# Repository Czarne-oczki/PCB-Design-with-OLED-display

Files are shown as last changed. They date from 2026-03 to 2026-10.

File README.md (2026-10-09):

# PCB Design with OLED display
# Overview
I am designing a 2-layer PCB that controls an OLED display via I2C, an SD card via SPI, and using a USB interface.

Zrzut ekranu 2026-10-08 175055

Zrzut ekranu 2026-10-08 175126

Zrzut ekranu 2026-10-08 174921

fourth board-1

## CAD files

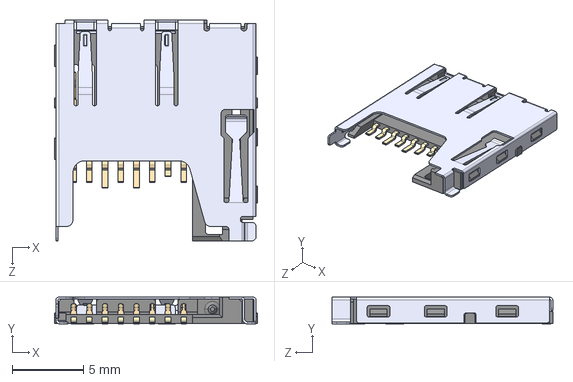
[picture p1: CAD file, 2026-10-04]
microsd/MEM2061-01-188-00-A_REVA.step
14.2 x 1.88 x 15.4 mm

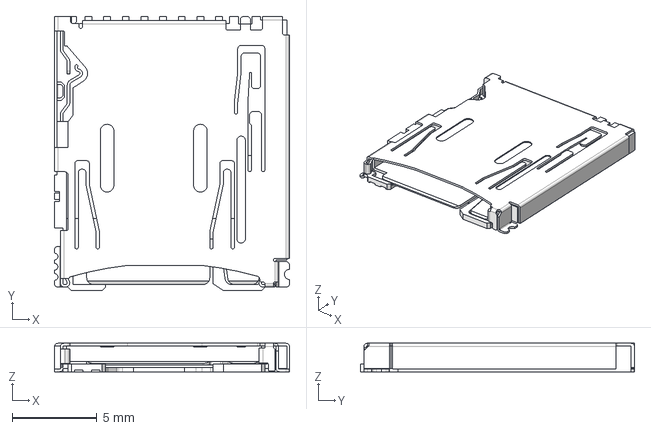
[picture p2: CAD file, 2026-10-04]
microsd3/DM3AT-SF-PEJM5.step
13.8 x 16.2 x 1.68 mm

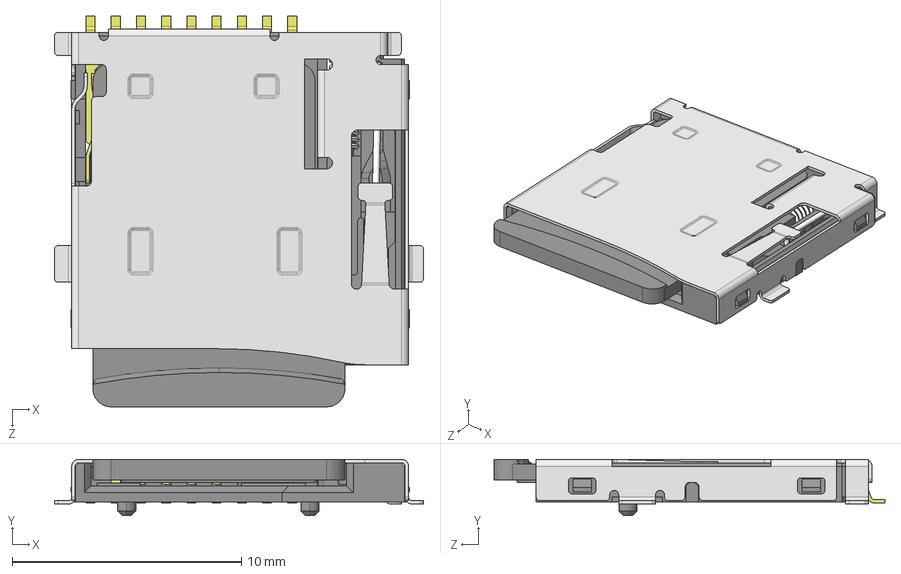
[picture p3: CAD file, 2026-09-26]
MicroSD_Socket.STEP
16.1 x 2.45 x 17.0 mm
Case^MicroSD_Socket
Insert^MicroSD_Socket
Brace^MicroSD_Socket
Spring^MicroSD_Socket
Lid^MicroSD_Socket
Pin_Middle^MicroSD_Socket x 5
Pin_Short^MicroSD_Socket
Pin_Long^MicroSD_Socket x 2
MicroSD_Card^MicroSD_Socket
Pin_CardIn^MicroSD_Socket

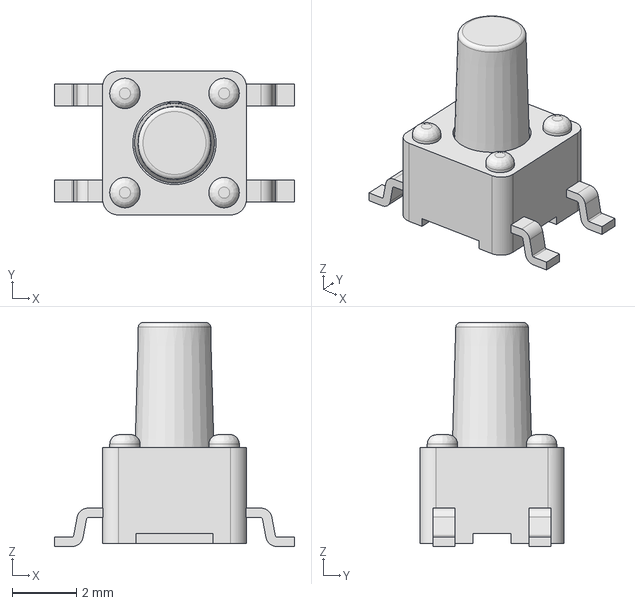
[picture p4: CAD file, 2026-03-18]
TL3305CF160QG.stp
7.50 x 4.50 x 7.00 mm

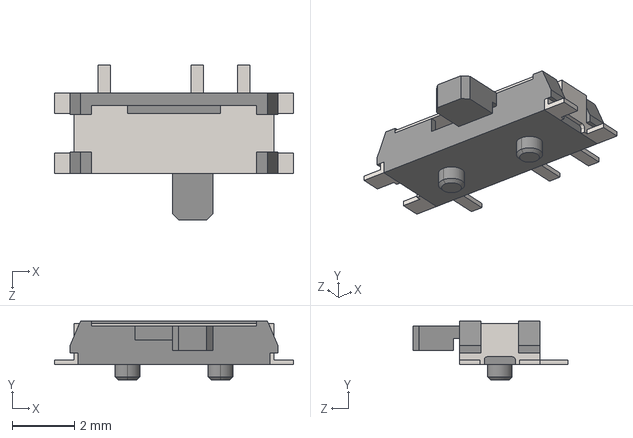
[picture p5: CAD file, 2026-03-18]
PCM12SMTR.stp
7.70 x 1.90 x 5.00 mm

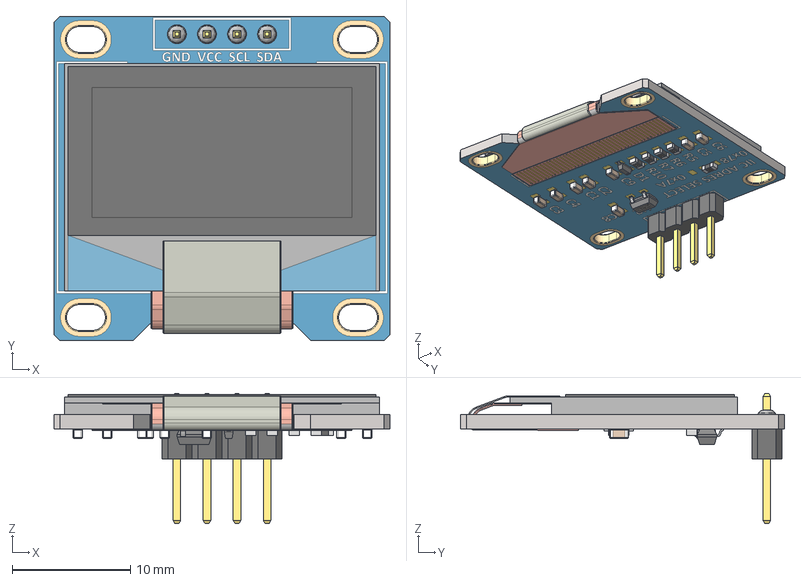
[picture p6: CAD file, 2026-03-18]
Pantalla OLED 0.96'' 128x64.stp
28.4 x 27.4 x 11.0 mm
SOT-23_TOR
RES_CR16_MTK_1 x 4
RES_CR16_MTK
SOD323F_DIO

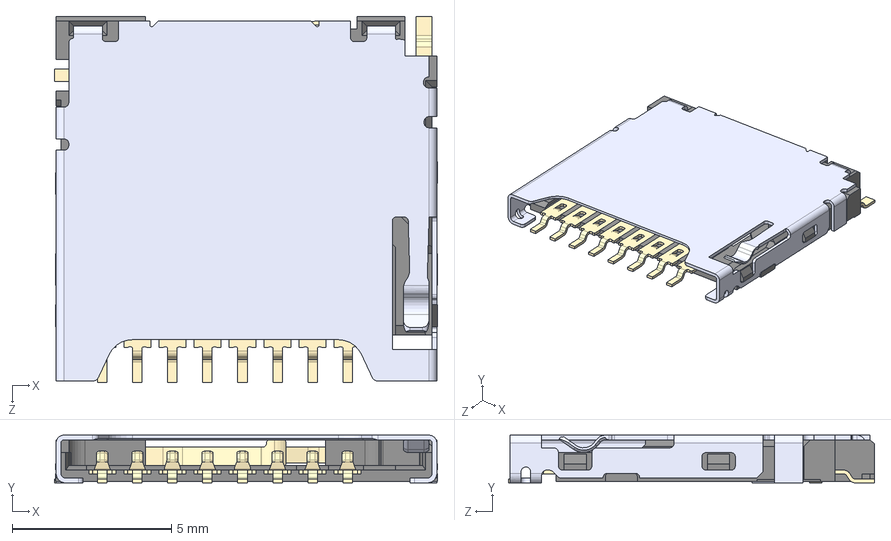
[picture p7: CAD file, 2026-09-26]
microsd2/1140084168.step
12.0 x 1.50 x 11.5 mm

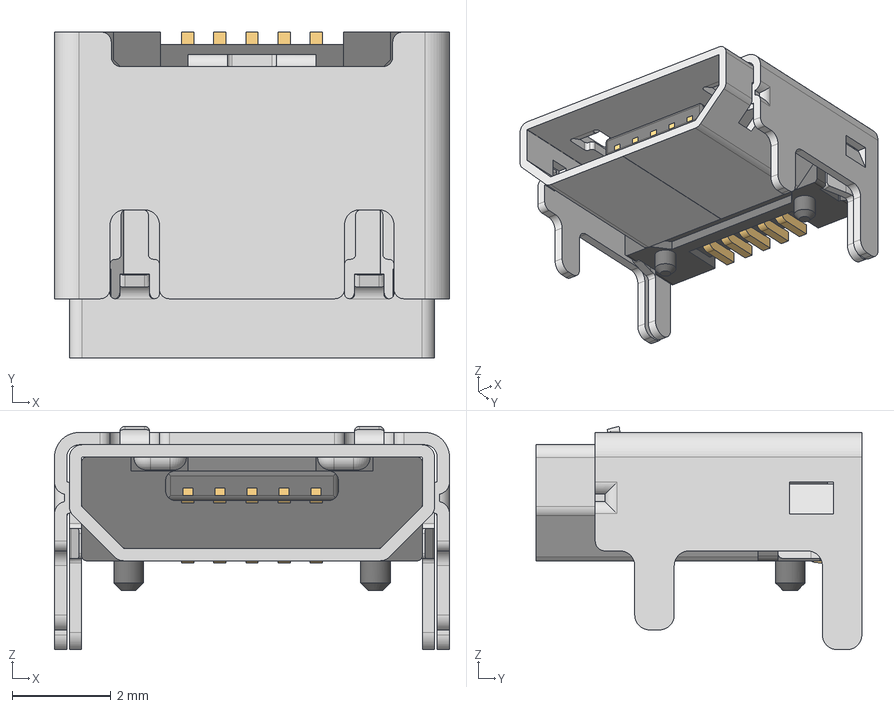
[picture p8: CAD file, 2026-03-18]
629105150521.stp
8.00 x 6.60 x 4.52 mm
629105150521_Housing
629105150521_Pin1 x 4
629105150521_Pin2
629105150521_Shielding2
629105150521_Shielding

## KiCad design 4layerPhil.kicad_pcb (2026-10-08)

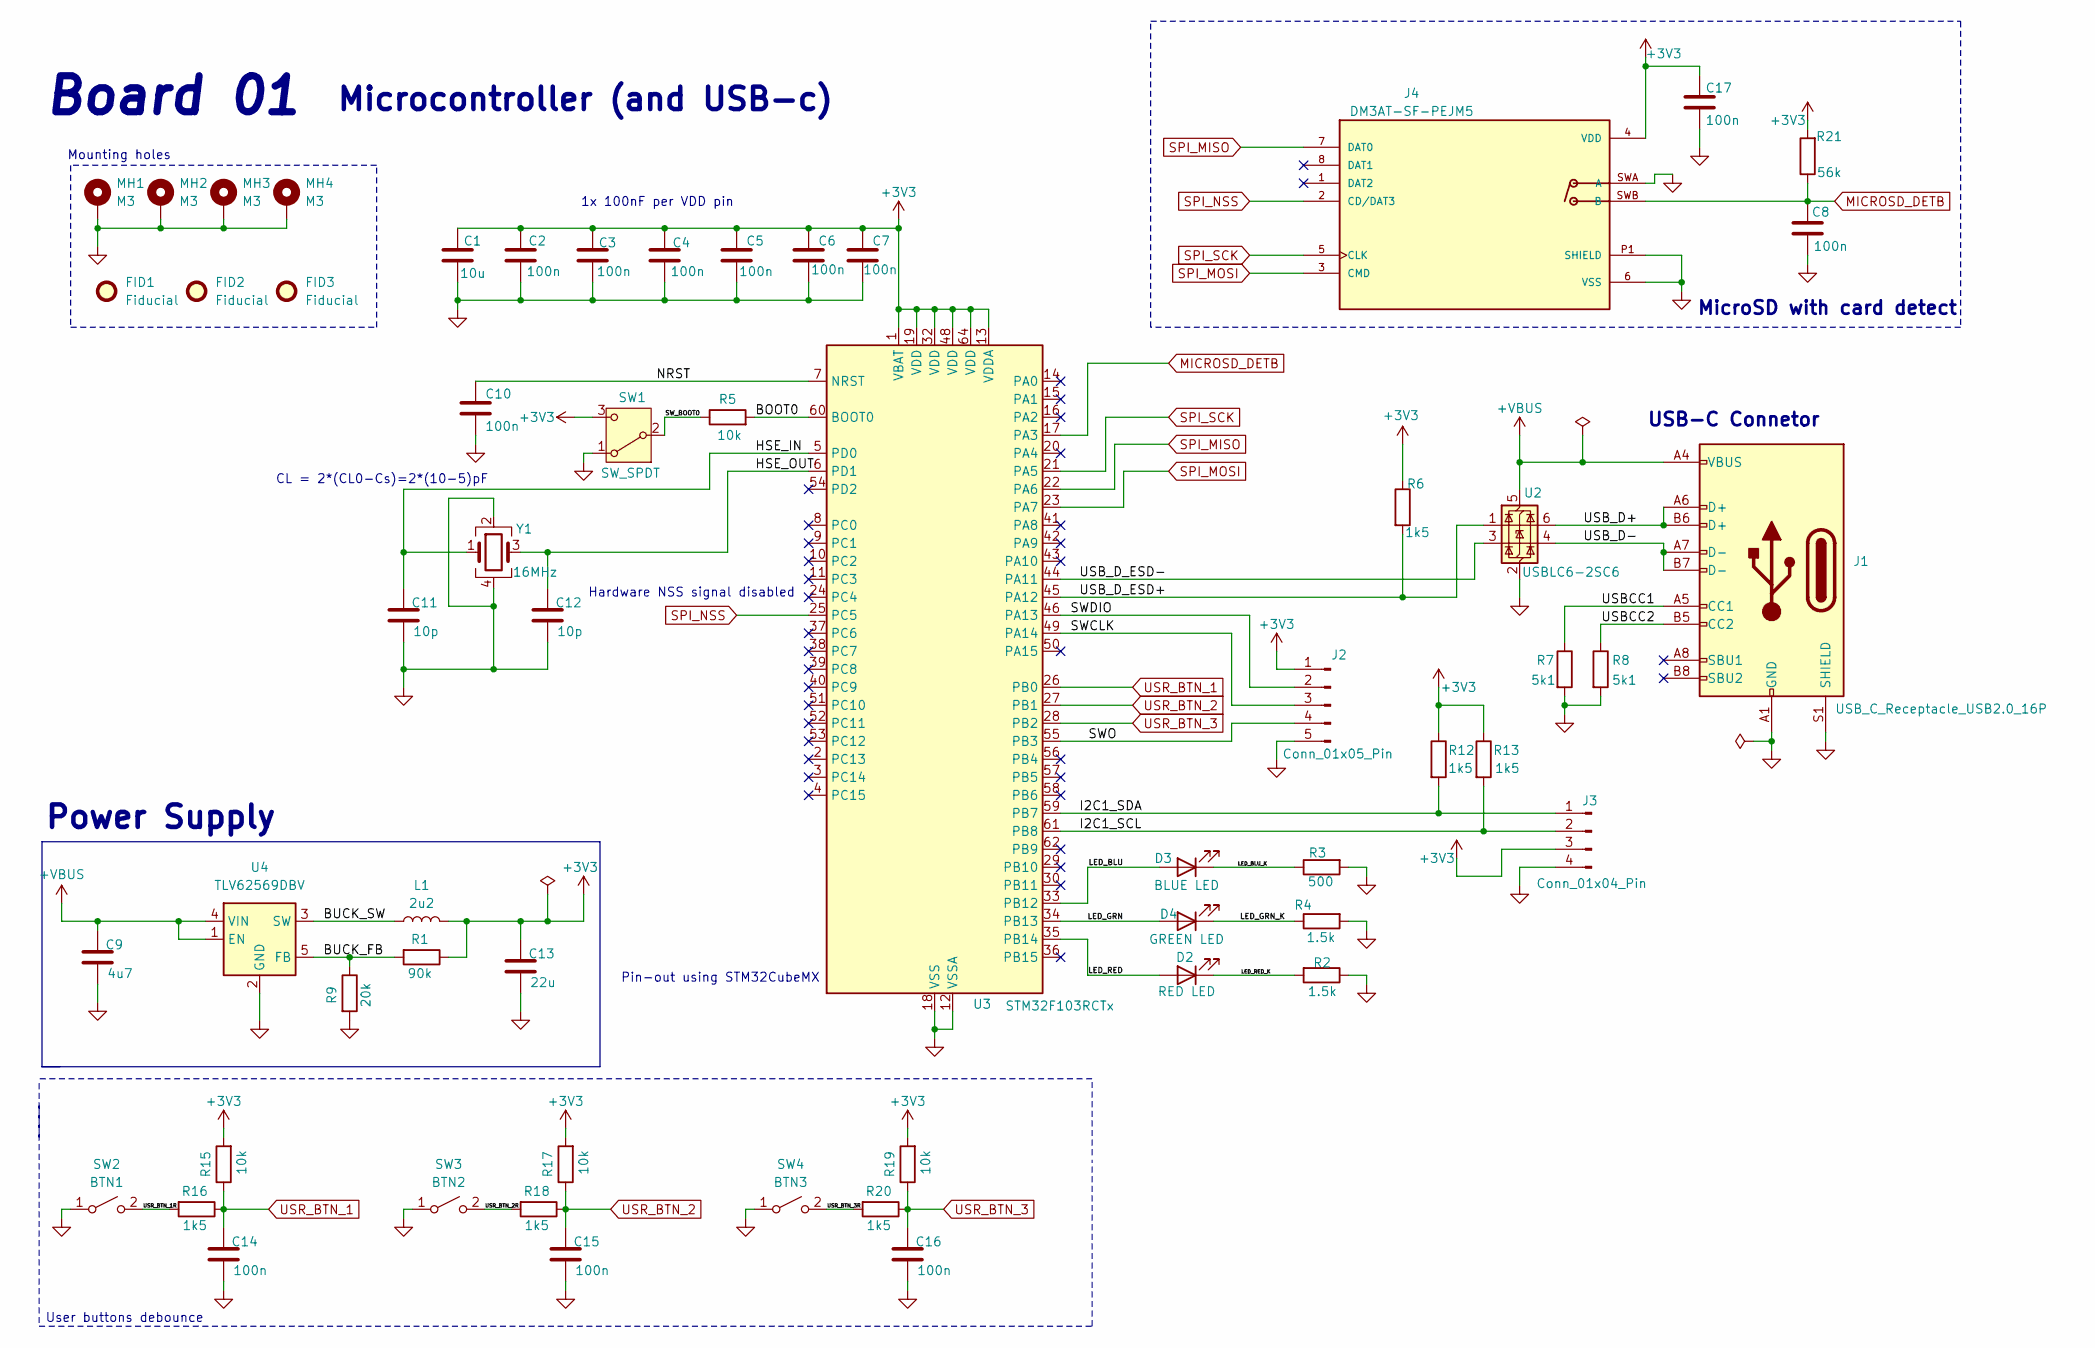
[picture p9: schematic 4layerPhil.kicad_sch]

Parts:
C1: 10u; C_0805_2012Metric
C2, C3, C4, C5, C6, C7, C8, C10, C14, C15, C16, C17: 100n; C_0603_1608Metric
C9: 4u7; C_0805_2012Metric
C11, C12: 10p; C_0603_1608Metric
C13: 22u; C_0805_2012Metric
D2: RED LED; LED_0603_1608Metric
D3: BLUE LED; LED_0603_1608Metric
D4: GREEN LED; LED_0603_1608Metric
FID1, FID2, FID3: Fiducial; Fiducial_1mm_Mask2mm
J1: USB_C_Receptacle_USB2.0_16P; USB_C_Receptacle_GCT_USB4105-xx-A_16P_TopMnt_Horizontal
J2: Conn_01x05_Pin; PinHeader_1x05_P2.54mm_Vertical
J3: Conn_01x04_Pin; PinHeader_1x04_P2.54mm_Vertical
J4: DM3AT-SF-PEJM5; HRS_DM3AT-SF-PEJM5; PARTREV 20200913
L1: 2u2; L_0805_2012Metric
MH1, MH2, MH3, MH4: M3; MountingHole_3.2mm_M3_Pad_Via
R1: 90k; R_0603_1608Metric
R2, R4: 1.5k; R_0603_1608Metric
R3: 500; R_0603_1608Metric
R5, R15, R17, R19: 10k; R_0603_1608Metric
R6, R12, R13, R16, R18, R20: 1k5; R_0603_1608Metric
R7, R8: 5k1; R_0603_1608Metric
R9: 20k; R_0603_1608Metric
R21: 56k; R_0603_1608Metric
SW1: SW_SPDT; SW_SPDT_PCM12
SW2: BTN1; SW_SPST_TL3305C
SW3: BTN2; SW_SPST_TL3305C
SW4: BTN3; SW_SPST_TL3305C
U2: USBLC6-2SC6; SOT-23-6
U3: STM32F103RCTx; LQFP-64_10x10mm_P0.5mm
U4: TLV62569DBV; SOT-23-5
Y1: 16MHz; Crystal_SMD_3225-4Pin_3.2x2.5mm

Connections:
+3V3: C1.1, C2.1, C3.1, C4.1, C5.1, C6.1, C7.1, C13.1, C17.1, J2.1, J3.3, J4.4 (VDD), L1.2, R1.1, R6.1, R12.1, R13.1, R15.2, R17.2, R19.2, R21.2, SW1.3 (C), U3.1 (VBAT), U3.13 (VDDA), U3.19 (VDD), U3.32 (VDD), U3.48 (VDD), U3.64 (VDD)
+VBUS: C9.1, J1.A4 (VBUS), J1.A9 (VBUS), J1.B4 (VBUS), J1.B9 (VBUS), U2.5 (VBUS), U4.1 (EN), U4.4 (VIN)
/BOOT0: R5.2, U3.60 (BOOT0)
/BUCK_FB: R1.2, R9.1, U4.5 (FB)
/BUCK_SW: L1.1, U4.3 (SW)
/HSE_IN: C11.1, U3.5 (PD0), Y1.1
/HSE_OUT: C12.1, U3.6 (PD1), Y1.3
/I2C1_SCL: J3.2, R13.2, U3.61 (PB8)
/I2C1_SDA: J3.1, R12.2, U3.59 (PB7)
/LED_BLU: D3.2 (A), U3.33 (PB12)
/LED_BLU_K: D3.1 (K), R3.1
/LED_GRN: D4.2 (A), U3.34 (PB13)
/LED_GRN_K: D4.1 (K), R4.1
/LED_RED: D2.2 (A), U3.35 (PB14)
/LED_RED_K: D2.1 (K), R2.2
/NRST: C10.1, U3.7 (NRST)
/SWCLK: J2.3, U3.49 (PA14)
/SWDIO: J2.2, U3.46 (PA13)
/SWO: J2.4, U3.55 (PB3)
/SW_BOOT0: R5.1, SW1.2 (B)
/USBCC1: J1.A5 (CC1), R7.1
/USBCC2: J1.B5 (CC2), R8.1
/USB_D+: J1.A6 (D+), J1.B6 (D+), U2.6 (I/O1)
/USB_D-: J1.A7 (D-), J1.B7 (D-), U2.4 (I/O2)
/USB_D_ESD+: R6.2, U2.1 (I/O1), U3.45 (PA12)
/USB_D_ESD-: U2.3 (I/O2), U3.44 (PA11)
/USR_BTN_1R: R16.2, SW2.2 (B)
/USR_BTN_2R: R18.2, SW3.2 (B)
/USR_BTN_3R: R20.2, SW4.2 (B)
GND: C1.2, C2.2, C3.2, C4.2, C5.2, C6.2, C7.2, C8.2, C9.2, C10.2, C11.2, C12.2, C13.2, C14.2, C15.2, C16.2, C17.2, J1.A1 (GND), J1.A12 (GND), J1.B1 (GND), J1.B12 (GND), J1.S1 (SHIELD), J2.5, J3.4, J4.6 (VSS), J4.P1 (SHIELD), J4.P2 (SHIELD), J4.P3 (SHIELD), J4.P4 (SHIELD), J4.SWA (A), MH1.1, MH2.1, MH3.1, MH4.1, R2.1, R3.2, R4.2, R7.2, R8.2, R9.2, SW1.1 (A), SW2.1 (A), SW3.1 (A), SW4.1 (A), U2.2 (GND), U3.12 (VSSA), U3.18 (VSS), U3.31 (VSS), U3.47 (VSS), U3.63 (VSS), U4.2 (GND), Y1.2, Y1.4
MICROSD_DETB: C8.1, J4.SWB (B), R21.1, U3.17 (PA3)
SPI_MISO: J4.7 (DAT0), U3.22 (PA6)
SPI_MOSI: J4.3 (CMD), U3.23 (PA7)
SPI_NSS: J4.2 (CD/DAT3), U3.25 (PC5)
SPI_SCK: J4.5 (CLK), U3.21 (PA5)
USR_BTN_1: C14.1, R15.1, R16.1, U3.26 (PB0)
USR_BTN_2: C15.1, R17.1, R18.1, U3.27 (PB1)
USR_BTN_3: C16.1, R19.1, R20.1, U3.28 (PB2)

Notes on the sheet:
Hardware NSS signal disabled
Mounting holes
USB-C Connetor
CL = 2*(CL0-Cs)=2*(10-5)pF
User buttons debounce
1x 100nF per VDD pin
Board 01
Power Supply
Microcontroller (and USB-c)
Pin-out using STM32CubeMX
MicroSD with card detect

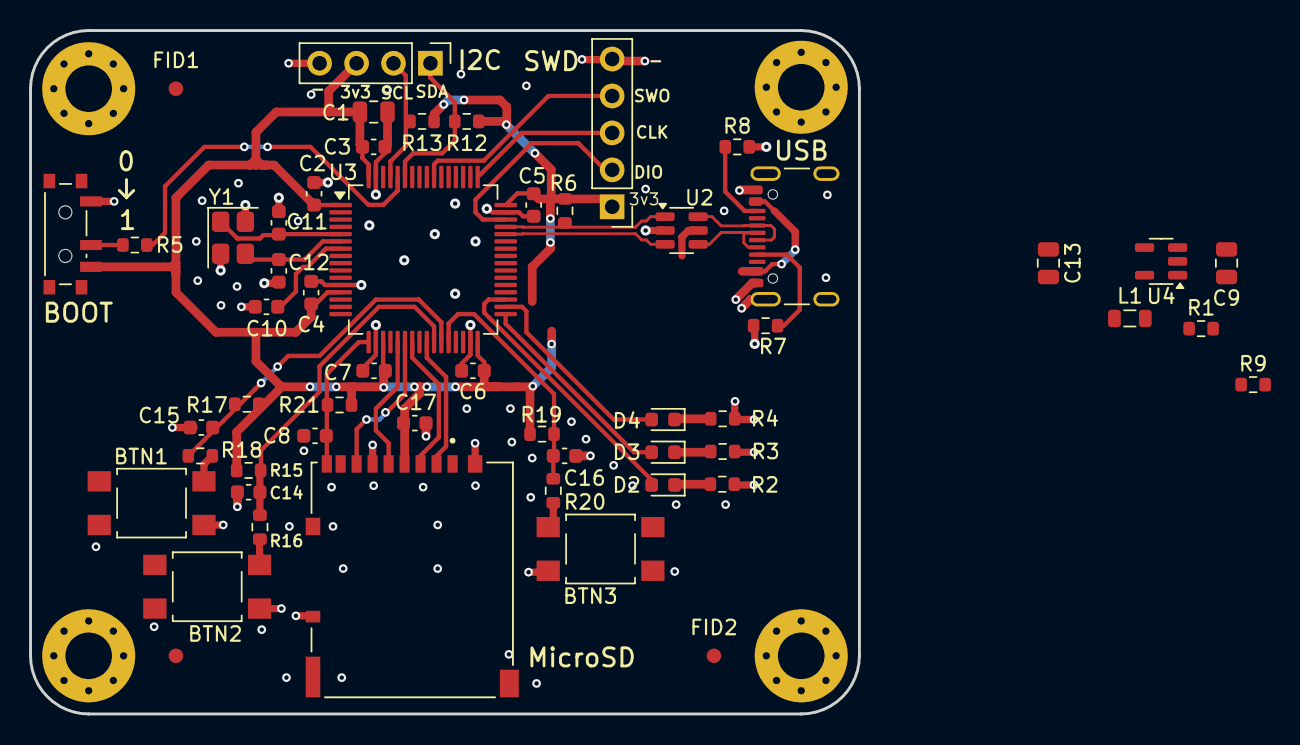
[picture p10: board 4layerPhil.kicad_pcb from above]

Board: 2 copper layers, 57.0 x 47.0 mm, 58 parts (0 on the bottom side), 38 nets.

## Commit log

2026-09-26 initial commit - different directory
    [1140084168.step, 4layerPhil.kicad_pcb, 4layerPhil.kicad_sch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]
2026-09-28 completed all signal routes, switched btn placemenets
    [4layerPhil.kicad_pcb, 4layerPhil.kicad_sch]
2026-09-29 added routes and viases
    [4layerPhil.kicad_pcb]
2026-09-29 different GND layer, started power supply section
    [4layerPhil.kicad_pcb]
2026-09-30 Preparation for changing LDO to impulse regulator, SWDIO to a correct connector etc.
    [4layerPhil.kicad_pcb, 4layerPhil.kicad_sch]
2026-10-01 Added gain
    [4layerPhil.kicad_pcb, 4layerPhil.kicad_sch]
2026-10-01 assigned VBUS and GND as power lines for type-c receptacle schematic
    [4layerPhil.kicad_pcb, 4layerPhil.kicad_sch]
2026-10-03 Switched from MicroB to USB Type-C and smaller changes
    [4layerPhil.kicad_pcb, 4layerPhil.kicad_sch]
2026-10-03 Created power supply circuit for new regulator, deleted ancient AMS1117
    [4layerPhil.kicad_pcb, 4layerPhil.kicad_sch]
2026-10-04 Added colours to schematic
    [4layerPhil.kicad_pcb, 4layerPhil.kicad_sch]
2026-10-04 New microSD card
    [1140084168.step, 4layerPhil.kicad_pcb, 4layerPhil.kicad_sch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]
2026-10-04 Added new microSD socket
    [1140084168.step]
2026-10-04 Added 3rd MicroSD footprint
    [DM3AT-SF-PEJM5.step]
2026-10-04 Managed to make the PCB ~5 mm smaller in both directions
    [4layerPhil.kicad_pcb, 4layerPhil.kicad_sch]
2026-10-05 Finished signal routing and layout, started power routing
    [4layerPhil.kicad_pcb, 4layerPhil.kicad_sch]
2026-10-08 Finished pcb routing and layout but preparing to change the regulator to a buck converter for better thermals
    [4layerPhil.kicad_pcb, 4layerPhil.kicad_sch]
2026-10-08 Removed LDO in favour of Buck converter, assigned footprints, ready to layout on the PCB
    [4layerPhil.kicad_pcb, 4layerPhil.kicad_sch]
2026-10-15 Added LM3671MF buck converter
2026-10-15 Added and laid out new power supply section with new buck converter
2026-11-02 Rerouted power routes under microSD socket
